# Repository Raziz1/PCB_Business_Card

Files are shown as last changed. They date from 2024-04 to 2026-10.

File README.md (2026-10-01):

# PCB Business Card 💳
The following project is a PCB designed as a business card. This card contains an integrated NFC tag that allows you to share your contact information wirelessly.

<p align="center">
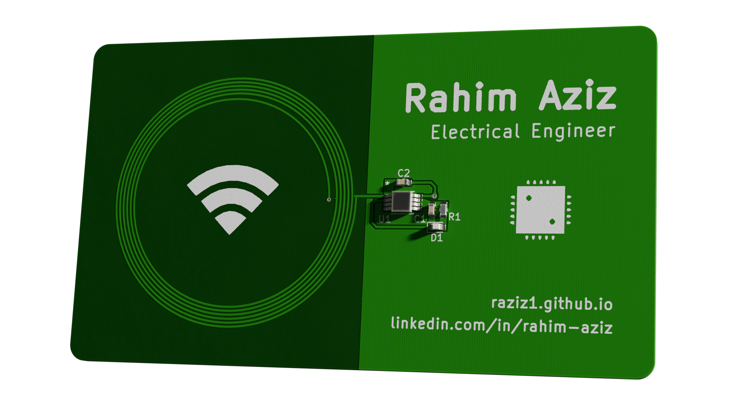
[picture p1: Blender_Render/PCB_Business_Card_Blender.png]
PCB Business Card PCB Business Card Render
    
</p>
<p align="center"><i>Blender Render</i></p>

## NFC Principle 🧲
<b>[NFC (Near Field Communication)](https://www.spiceworks.com/tech/networking/articles/what-is-near-field-communication/)</b> is a group of communication protocols that allows for low speed wireless communication between two electronic devices. 
* NFC communication occurs when both electronic devices are within a distance of 4cm or less. 
* NFC operates at 13.56 MHz on ISO/IEC 18000-3 air interface and at rates ranging from 106 kbit/s to 424 kbit/s.
* The transfer of data in NFC is bi-directional.
* NFC has a setup time of 0.1s. For reference, Bluetooth requires a setup time of 6s.
* NFC utilizes the phenomenon of inductive coupling between two electromagnetic coils.

<p align="center">
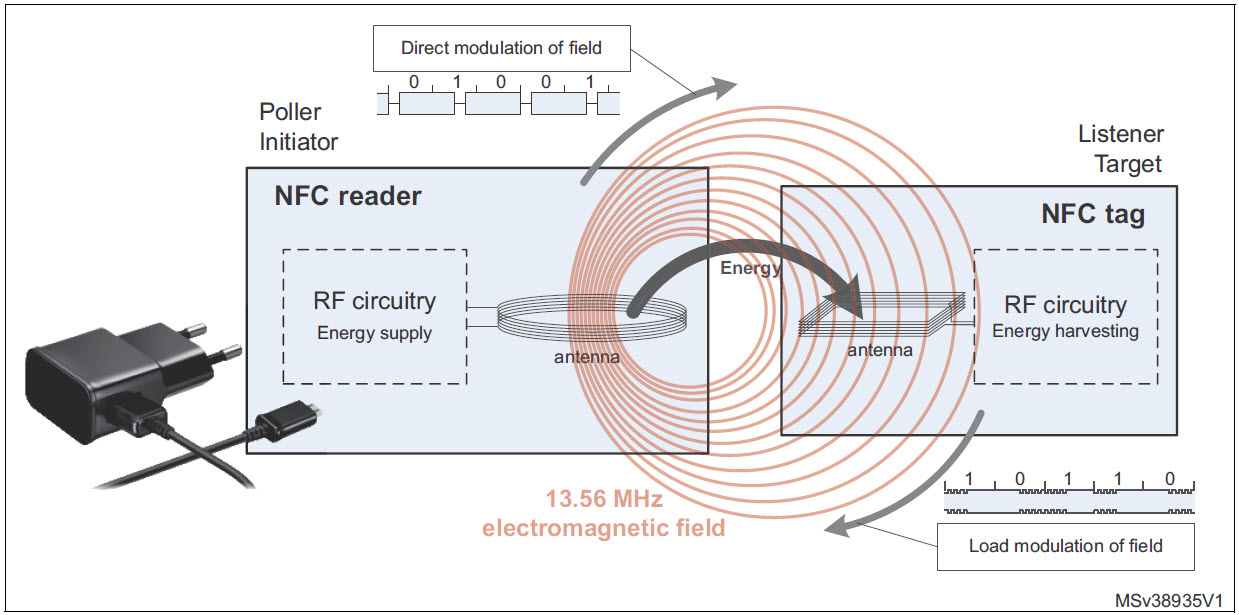
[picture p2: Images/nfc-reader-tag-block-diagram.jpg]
NFC Principle
    
</p>

## NFC IC 📶
THe NFC IC being used in this project is the [NT3H1101W0FTTJ](https://www.digikey.ca/en/products/detail/nxp-usa-inc/NT3H1101W0FTTJ/5347877).
* This chip is an NFC chip designed by NXP. It features I2C communication, energy harvesting, and field detection features. 
* It features 64 bytes of SRAM and 1kB of EEPROM memory. We can use the onboard memory to stored a personal website link for the user device to retrieve when communicating with the IC.
* Lastly with this chip, we can utilize the induced current to power the chip (i.e., energy harvesting).
* We can program the IC through the [NFC TagWriter by NXP](https://play.google.com/store/apps/details?id=com.nxp.nfc.tagwriter&hl=en_GB) app.

<p align="center">
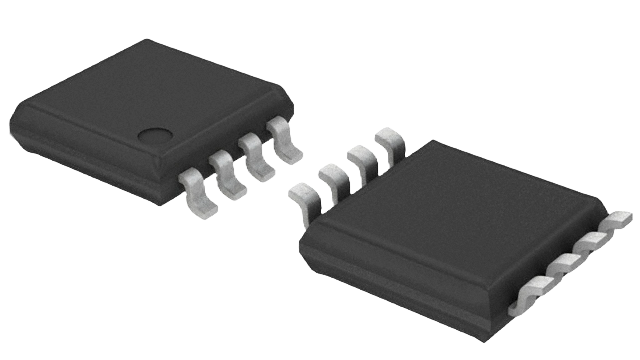
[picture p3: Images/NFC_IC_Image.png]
NFC IC NFC IC
    
</p>

## NFC Equivalent Circuit
The internet has a plethora of resources for antenna design. The two sources I will be referring to for this design are:
* [AN11276 - NXP Community](https://community.nxp.com/pwmxy87654/attachments/pwmxy87654/nfc/6155/1/AN11276.pdf)
* [AN2972 Application note How to design an antenna for dynamic NFC tags](https://www.st.com/resource/en/application_note/an2972-how-to-design-an-antenna-for-dynamic-nfc-tags-stmicroelectronics.pdf)

The figure below shows the equivalent electrical circuits of the dynamic NFC tag and its antenna.

<p align="center">
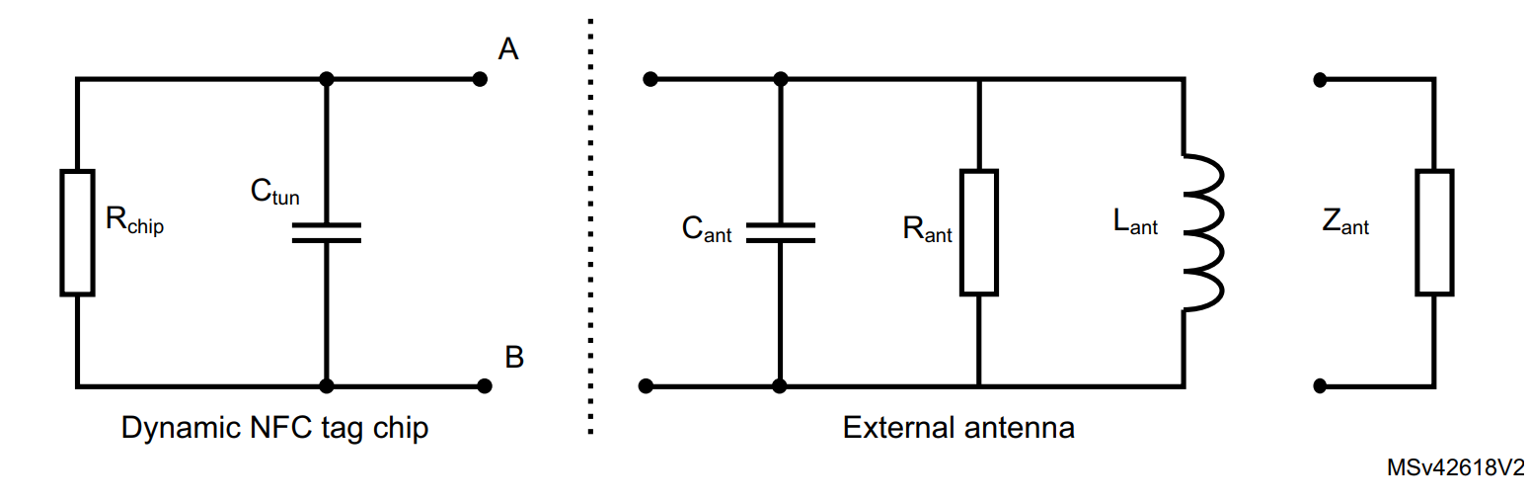
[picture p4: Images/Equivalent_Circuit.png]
NFC Equivalent Circuit
    
</p>

The above circuit can be simplified into an equivalent RLC circuit.

<p align="center">
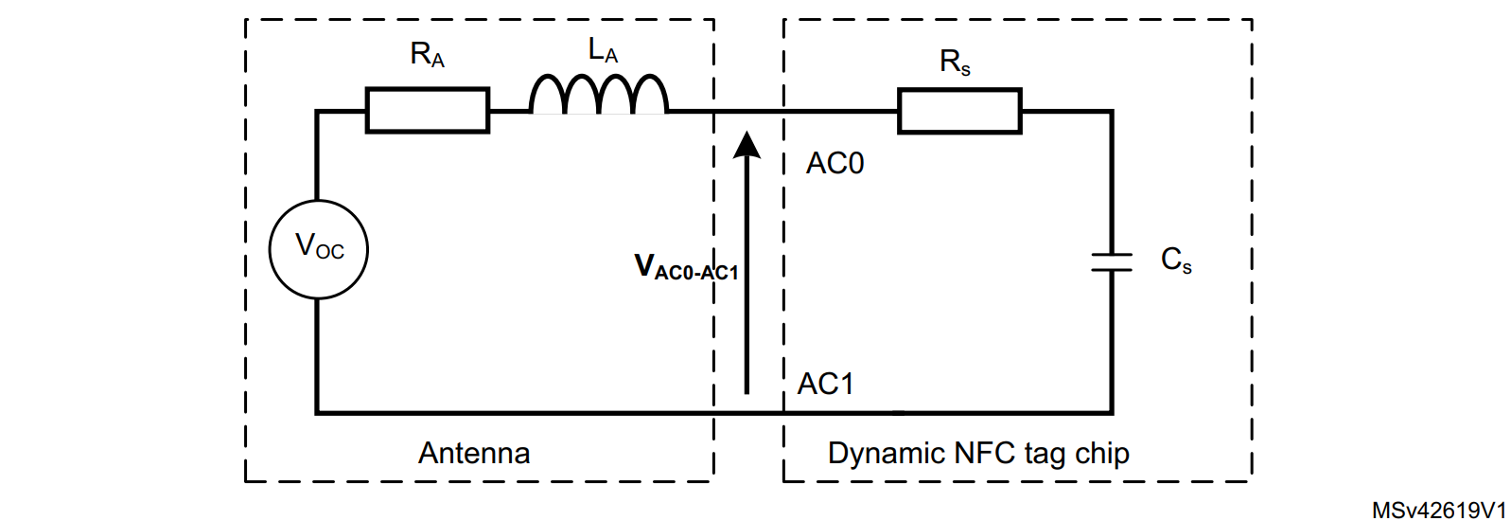
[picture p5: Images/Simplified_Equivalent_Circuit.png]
NFC RLC Circuit
    
</p>

### Resonance Frequency
Based on the simplified RLC circuit we can determine the resonant frequency. 
* Resonance frequency is the frequency (in hertz) in which a signal or power level can be carried, or couple from one device to another with no power or signal loss "ideally".
* $f_R=\frac{1}{2\cdot \pi \cdot \sqrt{L_{pc}\cdot C_{pl}}}$
    * $C_{pl}=C_{tun}+C_{ant}$

We know that for an NFC tag, the desired frequency is 13.56 MHz. We also know that the IC's parallel capacitance is 50 pF (from the datasheet). <i>Ignore the parasitic capacitance of the antenna for now; we will come back to that</i>. Based on this information, we can work backwards to determine the required inductance of the antenna.

$f_R=\frac{1}{2\cdot \pi \cdot \sqrt{L_{pc}\cdot C_{pl}}}$

$L_{pc}=\frac{1}{C_{pl}\left(2\pi f_R\right)^2}$

$L_{pc}=\frac{1}{5\cdot 10^{-11}\left(2\pi \cdot 13560000\right)^2} = 0.00000275518$

$L_{pc}=0.00000275518\:H=\:2.75518\:uH$

## Antenna Design 📡
We can now design an NFC antenna based on the desired inductance calculated above. To design the antenna I referred to various resources to confirm my calculations. 

### NXP Spiral Antenna Calculation
The [AN11276 NTAG Antenna Design Guide](https://community.nxp.com/pwmxy87654/attachments/pwmxy87654/nfc/6155/1/AN11276.pdf) provides the following information to design an antenna. 

<p align="center">
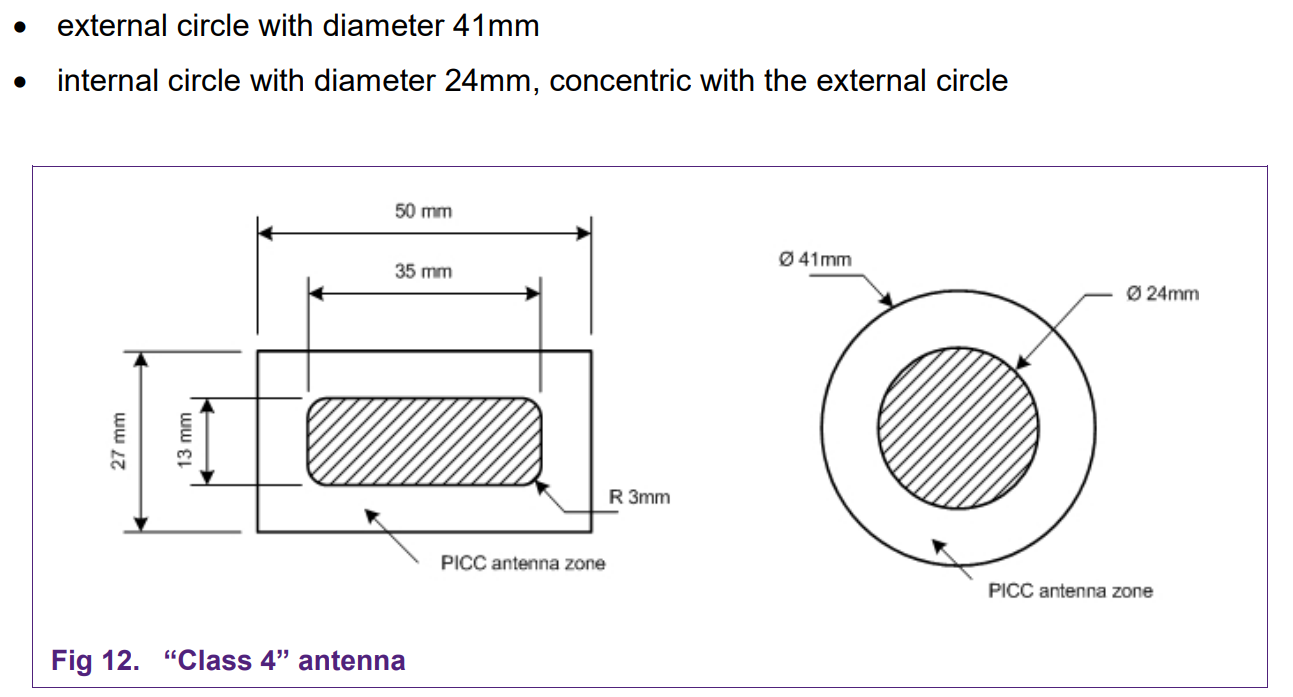
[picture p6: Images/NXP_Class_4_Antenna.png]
    
</p>
<p align="center"><i>NXP Class 4 Antenna Design Recommendation</i></p>

<p align="center">
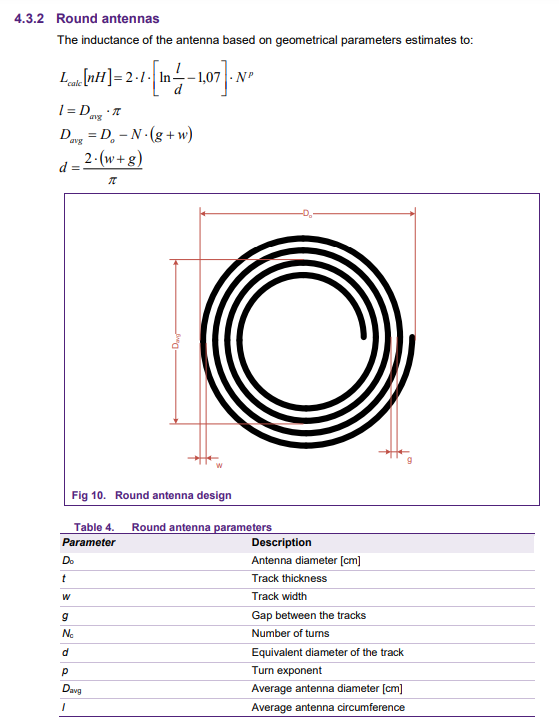
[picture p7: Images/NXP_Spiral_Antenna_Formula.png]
NXP Spiral Formula
    
</p>
<p align="center"><i>NXP Round Antennas Formula</i></p>

I utilized the [Antenna_Shape_Calculator](/Resource_Documents/Antenna_Shape_Calculator.xlsx) excel document to calculate the geometric parameters. They were as follows:
* $D_0 = 41mm$
* $t = 35um$
* $w = 300um$
* $g = 300um$
* $Nant = 6\:turns$
* $L_{calc} = 2.754uH$

### STM Spiral Antenna Calculation
The [AN2972 Application note](https://www.st.com/resource/en/application_note/an2972-how-to-design-an-antenna-for-dynamic-nfc-tags-stmicroelectronics.pdf) provides the following information to design an antenna. 

<p align="center">
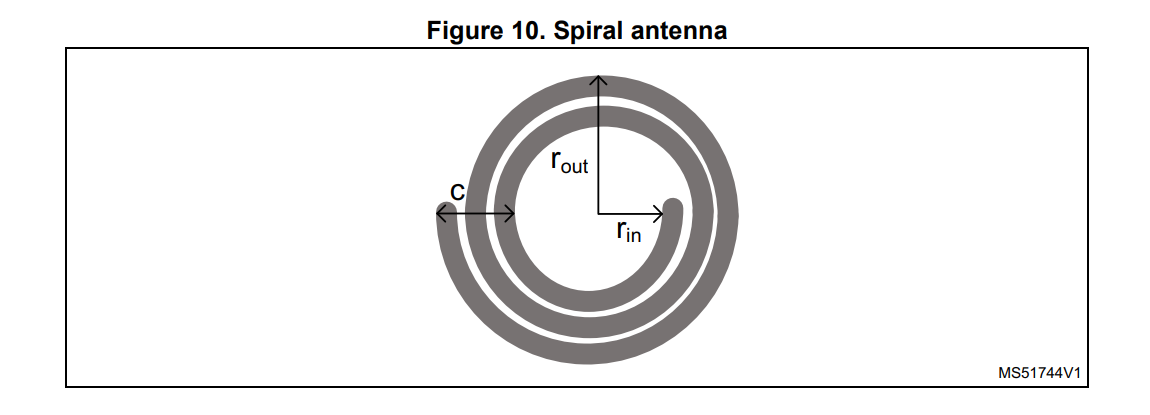
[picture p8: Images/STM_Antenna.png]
    
</p>
<p align="center"><i>STM Spiral Antenna Design</i></p>

<p align="center">
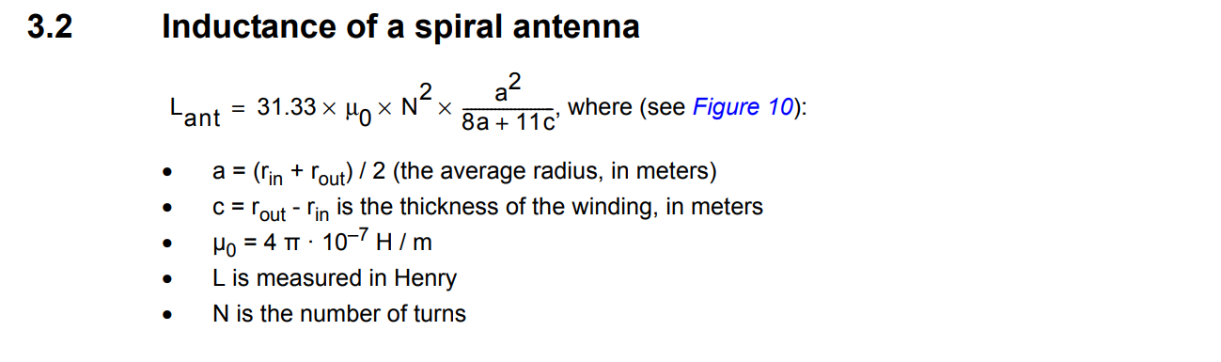
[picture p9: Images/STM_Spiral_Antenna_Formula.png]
STM Spiral Formula
    
</p>
<p align="center"><i>STM Spiral Antennas Formula</i></p>

I utilized the [Antenna_Shape_Calculator](/Resource_Documents/Antenna_Shape_Calculator.xlsx) excel document to calculate the geometric parameters. They were as follows:
* $r_{in} = 17.5mm$
* $r_{out} = 20.5mm$
* $Nant = 6\:turns$
* $L_{calc} = 2.766uH$

### Missing Parameters 
We are not quite ready to complete the design. Looking back at the equivalent circuit, we are still missing a few parameters: antenna capacitance, antenna resistance, and the NFC IC resistance. Typically, these parameters are determined by measuring the actual physical circuit design. For a guide on how to measure these parameters, check out the following link: --> [Guide to designing antennas for the NTAG I2C plus](https://community.nxp.com/t5/NXP-Designs-Knowledge-Base/Guide-to-designing-antennas-for-the-NTAG-I2C-plus/ta-p/1104729).  Nevertheless, we can make some rough estimations by utilizing various tools.

* Antenna resistance - By using a parasitic resistance tool in KiCad, we can calculate this parameter. According to the tool, the parasitic resistance was 1.17 ohms. 
* Antenna capacitance - By utilizing the [NXP NFC Antenna Tool](https://community.nxp.com/t5/NFC/bd-p/nfc/page/4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.) we can roughly estimate this parameter. This tool does not support spiral designs, but we can use the rectangular design to estimate this parameter. According to the tool, the parasitic capacitance was 1.9 pF.
* NFC IC Resistance - Assuming the voltage should drop entirely across the IC, we can consider this resistance to be infinitely large. For our purposes, we will estimate it to be 100k ohms.

<p align="center">
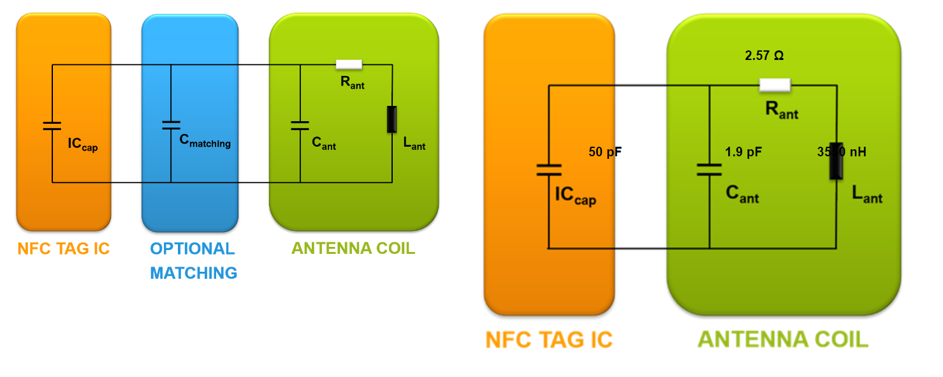
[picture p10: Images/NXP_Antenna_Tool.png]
NXP NFC Antenna Tool
    
</p>
<p align="center"><i>NXP NFC Antenna Tool</i></p>

## Simulation
We can now work our way backwards to verify the parameters we calculated above. By rebuilding the equivalent circuit with these parameters in LTSpice, we can verify the resonance frequency. According to the simulation below, the resonance frequency is 13.35 MHz. This should be adequate for NFC; alternatively, we can target an inductance of 2.5-2.6 uH to achieve a resonance frequency that is closer to 13.56 MHz. Furthermore, an optional tuning capacitor can be added to get closer to 13.56 MHz.

<p align="center">
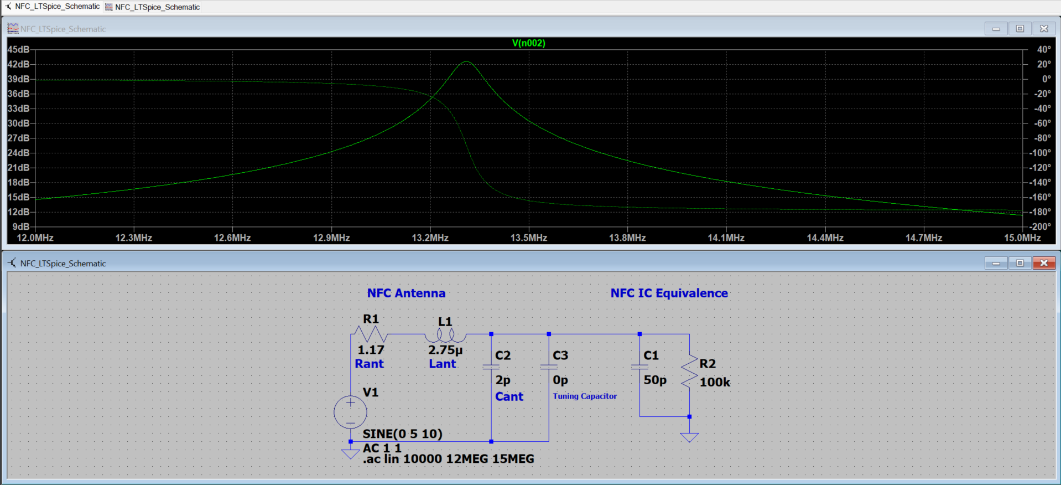
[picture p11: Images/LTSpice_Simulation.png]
LTSpice Simulation
    
</p>
<p align="center"><i>LTSpice Simulation</i></p>

I decided to rerun the simulation and redesign the antenna parameters ($D_0 = 39mm$) to target an inductance of 2.576uH. This gives us more headroom to account for any imperfections in the manufacturing process. This allows us to use a tuning capacitor to bring the resonance frequency down and closer to 13.56 MHz.  

<p align="center">
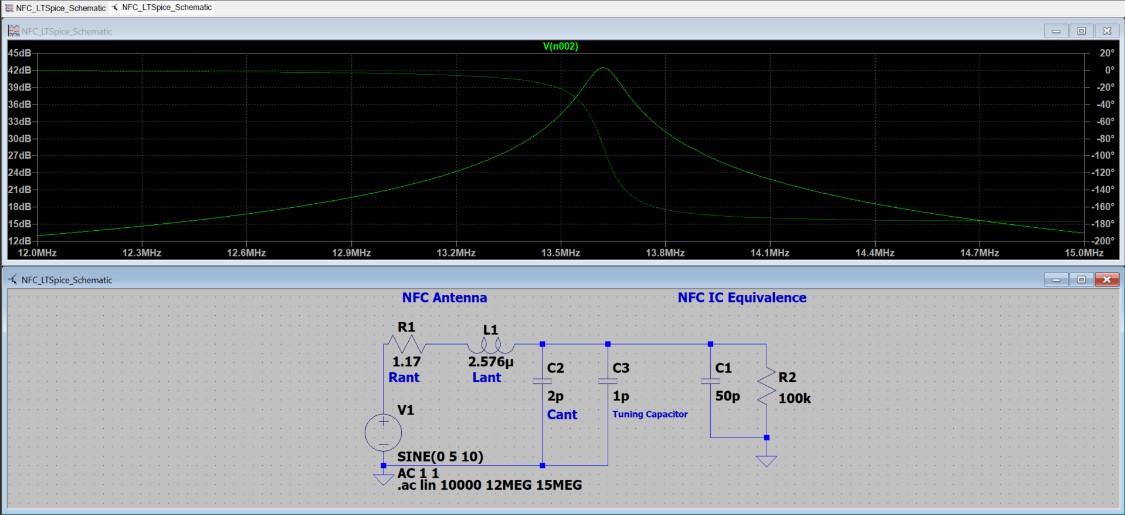
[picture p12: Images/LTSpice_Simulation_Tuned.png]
LTSpice Simulation Tuned
    
</p>
<p align="center"><i>LTSpice Simulation with Tuning Capacitor</i></p>

### Electromagnetic Simulation 🧲
Antennas are typically simulated using electromagnetic simulation software to predict and optimize their real-world performance. A variety of tools are available, such as:
* Ansys HFSS/Maxwell - The student edition is free but has limitations
* Solidworks CST Microwave -  The student edition is free but has limitations
* openEMS
* MATLAB Antenna Toolbox

For this design, I chose to work with MATLAB’s Antenna Toolbox and RF Toolbox, as I did not yet have the experience to effectively use industry-grade tools like HFSS or CST.

#### MATLAB Antenna Toolbox
<p align="center">
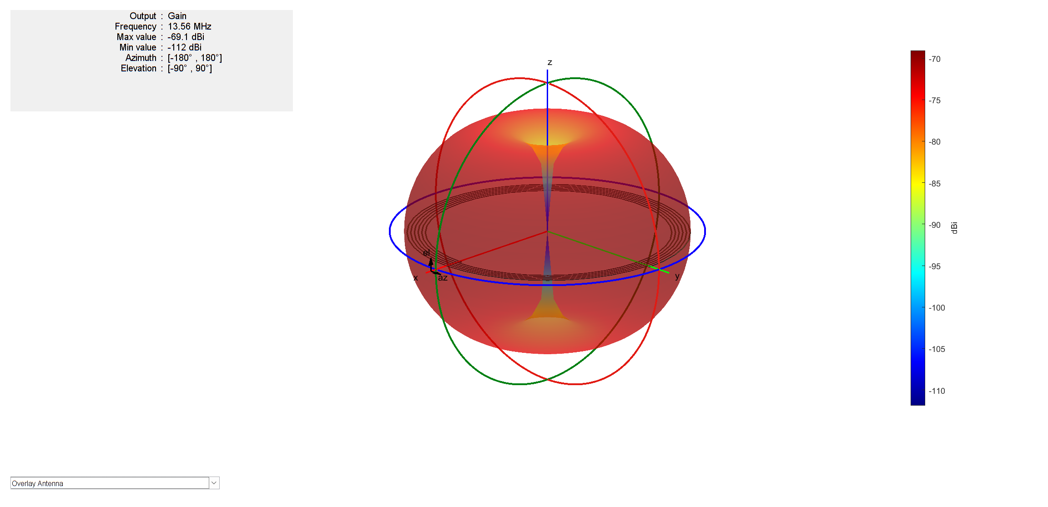
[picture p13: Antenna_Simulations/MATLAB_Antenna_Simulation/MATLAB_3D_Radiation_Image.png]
MATLAB Antenna Simulation
    
</p>
<p align="center"><i>MATLAB 3D Radiation Pattern</i></p>

After spending several days experimenting with the MATLAB script from the repository, I was unsuccessful in reproducing a clear resonance at 13.56 MHz. I tried designing the antenna directly in the Antenna Toolbox, carefully defining spiral coil parameters, trace width, spacing, and substrate properties. I also attempted to import the PCB layout into the PCB Antenna Toolbox using the gerber files of the actual NFC coil. Despite these efforts, the desired resonance could not be achieved. Following a discussion with [Umar on the MATLAB Answers forum](https://www.mathworks.com/matlabcentral/answers/2180231-matlab-nfc-antenna-simulation?s_tid=srchtitle), it was clarified that the limitation lies in the software itself for this specific application:

>* *"MATLAB’s Antenna Toolbox is designed for far-field radiation analysis, not near-field inductive coupling. NFC, however, operates in the reactive near-field, where antennas behave as coupled inductors rather than radiating elements. The S11 parameters calculated in MATLAB inherently assume radiation losses, which do not accurately represent NFC coil physics."* *

At this stage, Umar provided a toolbox-free MATLAB script that verified the design using RF first principles, which is available in the repository. The script addressed the following calculations:
* Inductance using Wheeler’s formula (adapted to spiral coil + substrate corrections)
* AC + DC resistance including skin effect and dielectric loss
* Impedance of the NFC IC (modeled as parallel R + C)
* Combined system impedance and S11 over a narrower frequency sweep
* Determination of resonant frequency (by finding minimum imaginary part)
* Computation of required tuning capacitance
* Quality factor (Q), VSWR, bandwidth, return loss, Smith chart, etc.
* Using this method, Umar was able to detect a resonance around 11.81 MHz (≈ 12.9% error relative to target) with realistic inductance, resistance, and matching parameters. 

<p align="center">
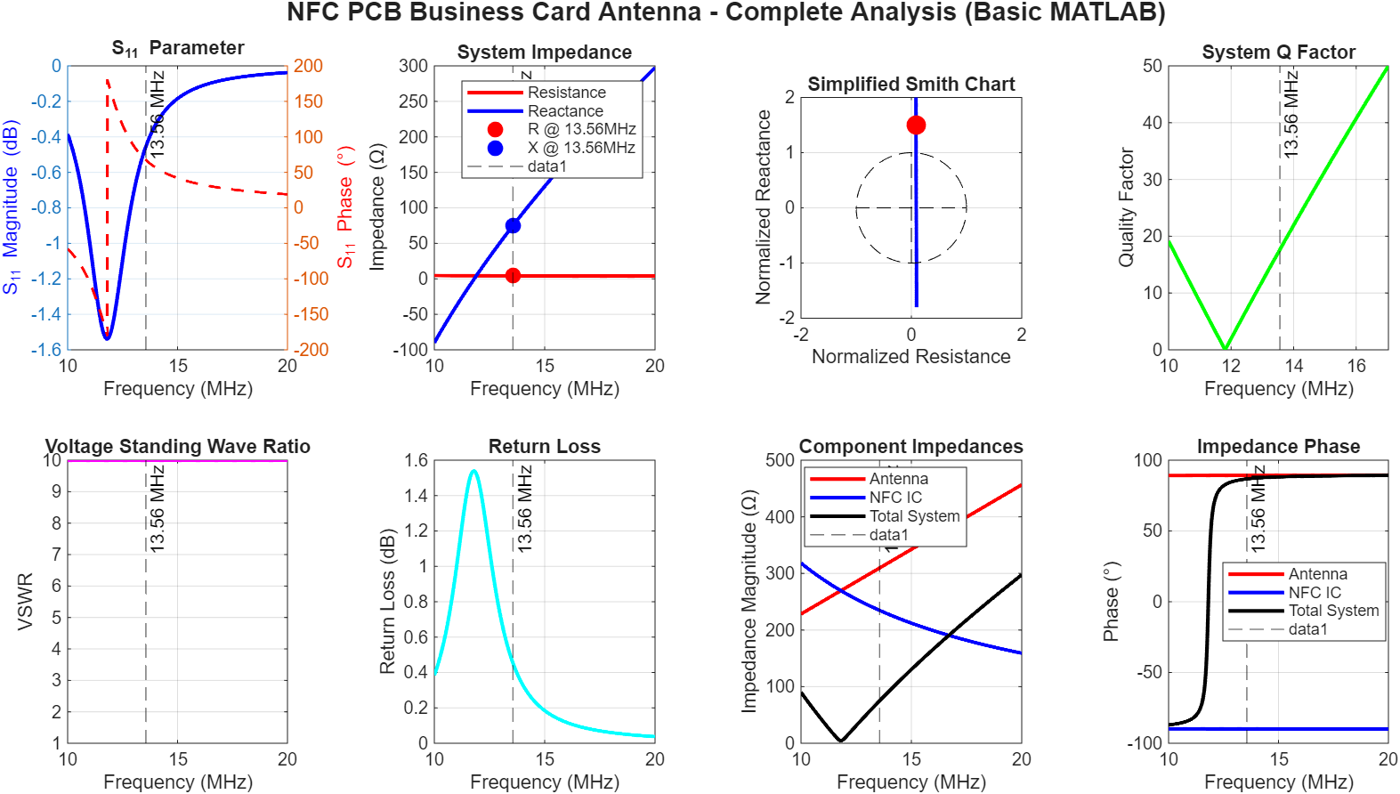
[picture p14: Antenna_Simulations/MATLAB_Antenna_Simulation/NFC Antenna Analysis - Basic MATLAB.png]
Umar Script Output
    
</p>
<p align="center"><i>Umar Script Output</i></p>

## PCB Design
For the final design of the antenna I ended up settling on the following parameters:
* $D_0 = 39mm$
* $t = 35um$
* $w = 300um$
* $g = 300um$
* $Nant = 6\:turns$
* $L_{calc} = 2.576uH$
* $R_{ant} = 1.17\:ohms$
* $C_{ant} = 2pF$
* $Simulated\:resonance\:frequency:\:13.75 MHz$ 
    * *Without Tuning Capacitor*

For the schematic, I borrowed the idea of an LED indicator for the energy harvesting circuit from the [PCB Business Card With NFC](https://www.instructables.com/PCB-Business-Card-With-NFC/). The capacitor is to guarantee operation during RF communication. The resistor value was chosen to limit the current going through the LED. The value was determined by using the following equation:
* $R\:=\:\frac{V_{CC}-V_{LED}}{I_{LED}}=\frac{3.3-2}{0.02} = 65Ω$

<p align="center">
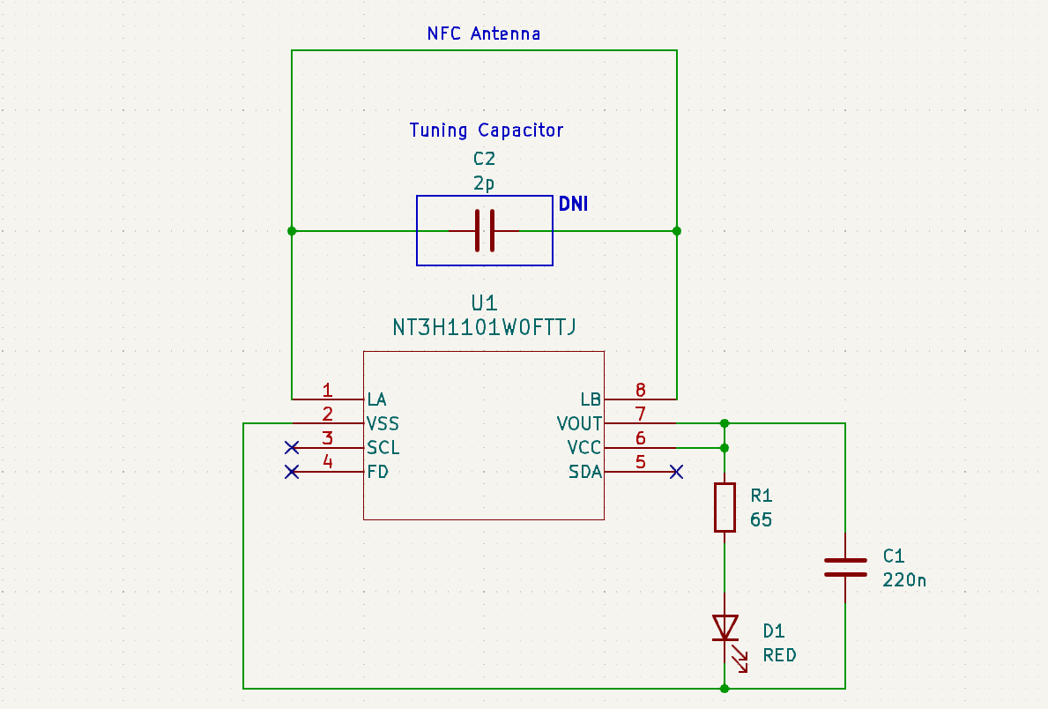
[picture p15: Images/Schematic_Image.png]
KiCad Schematic Design
    
</p>
<p align="center"><i>Schematic Design</i></p>
<p align="center">
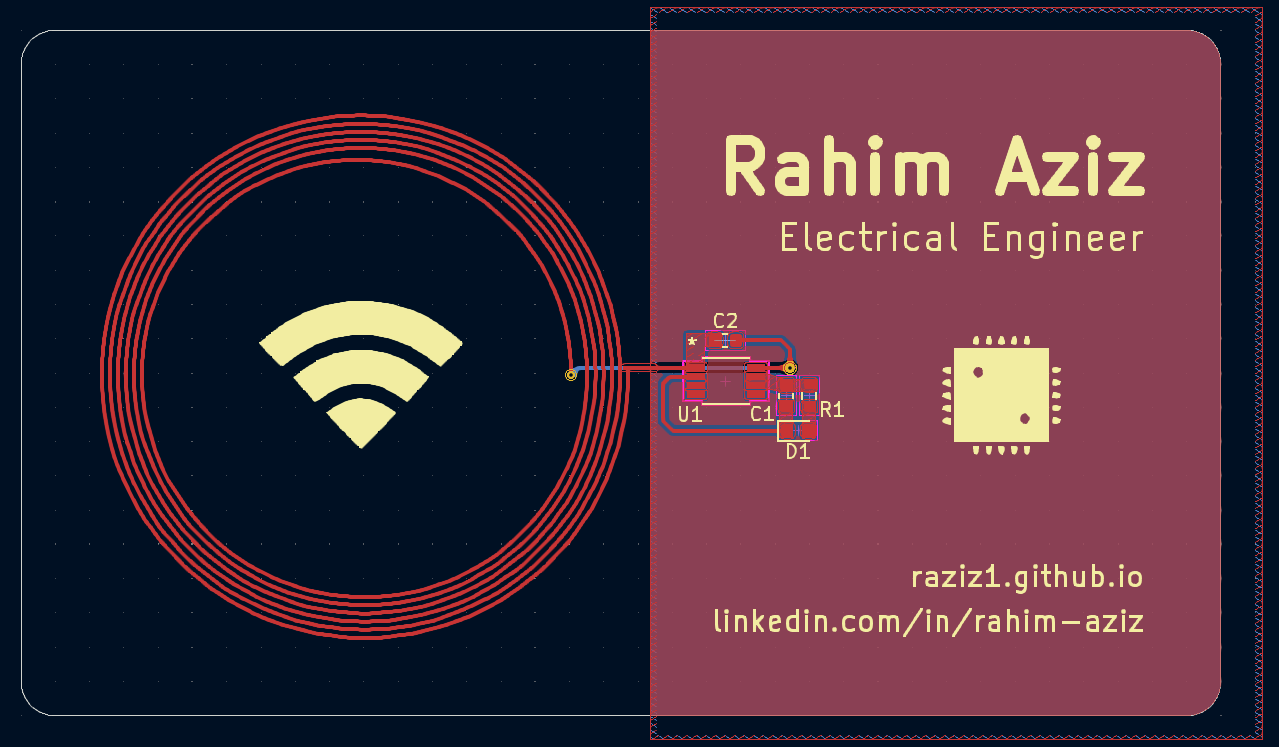
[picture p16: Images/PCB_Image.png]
KiCad PCB Design
    
</p>
<p align="center"><i>PCB Design</i></p>

## Final BOM 📃
* [NT3H1101W0FTTJ - IC RFID TRANSP 13.56MHZ 8TSSOP](https://www.digikey.ca/en/products/detail/nxp-usa-inc/NT3H1101W0FTTJ/5347877)
* [150060VS75000 - LED GREEN CLEAR 0603 SMD](https://www.digikey.ca/en/products/detail/w%C3%BCrth-elektronik/150060VS75000/4489906)
* [C0603C224J4REC7867 - CAP CER 0603 220NF 16V X7R 5%](https://www.digikey.ca/en/products/detail/kemet/C0603C224J4REC7867/8643651)
* [CRCW060364R9FKEA - RES SMD 64.9 OHM 1% 1/10W 0603](https://www.digikey.ca/en/products/detail/vishay-dale/CRCW060364R9FKEA/1174533)
* [GRM0335C1E1R5BA01D - CAP CER 1.5PF 25V C0G/NP0 0201 (0603 Metric)](https://www.digikey.ca/en/products/detail/murata-electronics/GRM0335C1E1R5BA01D/4358584)

## Manufacturing 🪛
I ordered the board through PCBWay by using the [KiCAD plugin](https://www.pcbway.com/blog/News/PCBWay_Plug_In_for_KiCad_3ea6219c.html). I assembled and soldered the components on the board myself. 

For the PCBWay specification selection I chose the following options:
* Layers: 2
* Material: FR-4
* FR4-TG: TG130-140
* Thickness: 1.6mm
* Min track/spacing: 5/5mil
* Solder mask: Green
* Silkscreen: White
* Edge connector: No
* Surface finish: HASL with lead
* Via process: Tenting vias
* Finished copper: 1 oz Cu
* Remove product Num: No

<p align="center">
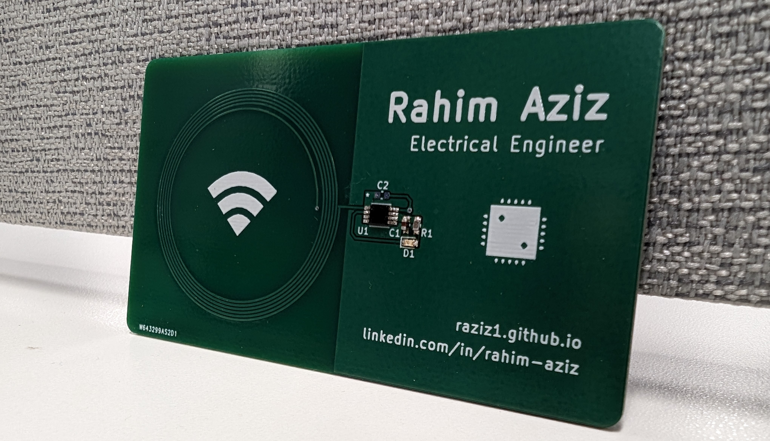
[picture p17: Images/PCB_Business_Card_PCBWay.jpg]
PCBWay PCB
    
</p>
<p align="center"><i>Final Product</i></p>

## Programming 💻
Lastly, I programed the IC through the [NFC TagWriter by NXP](https://play.google.com/store/apps/details?id=com.nxp.nfc.tagwriter&hl=en_GB) app.

<p align="center">
    PCB GIF
</p>
<p align="center"><i>PCB in Action!</i></p>

> [!CAUTION]
> ### iPhone Compatibility & Energy Harvesting Limit
>
> During real-world testing, this card worked reliably on Android devices but failed to trigger background NFC reading on iPhones.
>
> * **Polling Fields:** iPhones emit low-energy, brief polling bursts to conserve battery, whereas many Android phones broadcast significantly stronger, higher-energy continuous RF fields.
> * **Energy Starvation:** When attempting to harvest energy from an iPhone, the on-board LED circuit drew too much current. This collapsed the harvested voltage rail before the NT3H1101’s digital core could boot and complete its initial communication handshake.
>
> #### Circuit Current Consumption
> Based on the populated components ($R = 64.9\ \Omega$ and a green LED with $V_f \approx 2.0\text{ V}$), the branch demands:
>
> $$I_{LED} = \frac{V_{OUT} - V_{LED}}{R} = \frac{3.3\text{ V} - 2.0\text{ V}}{64.9\ \Omega} \approx 20\text{ mA}$$
>
> #### Datasheet Limit
> According to the NXP NT3H1101/1201 datasheet:
>
> > *"The voltage and current from the energy harvesting depend on various parameters, such as the strength of the RF field, the tag antenna size, or the distance from the NFC device. At room temperature, NTAG I2C could provide typically 5 mA at 2 V on the VOUT pin with an NFC Phone.*
> >
> > *Operating NTAG I2C in energy harvesting mode requires a number of precautions:*
> > * *A significant capacitor is needed to guarantee operation during RF communication. The total capacitor between VOUT and GND shall be in the range of 150nF to 200 nF.*
> >
> > *Note that increasing the output current on the Vout decreases the RF communication range."*
>
> Because the IC typically delivers only up to **5 mA at 2 V** under smartphone coupling, an active load demanding **~20 mA** collapses the harvested rail on lower-power emitters like iPhones.
>
> **Fix:** Leaving the LED/resistor unpopulated (or increasing the resistor to $\ge 1\text{--}2\text{ k}\Omega$ to limit current below $1\text{ mA}$) immediately restores instant background read compatibility on iPhones.

## Characterization 🔬
Finally, I wanted to characterize the response of the circuit using my Analog Discovery 2 - USB oscilloscope. In particular, I aimed to characterize and visualize the difference in responses when the circuit had and didn't have a tuning capacitor.

### No Tuning Capacitor

The first order of business was to utilize the network analyzer feature on the Analog Discovery 2. By attaching the wave generator on one end of the antenna and probing on the other we could sweep through various frequencies and observe the circuits response.

<p align="center">
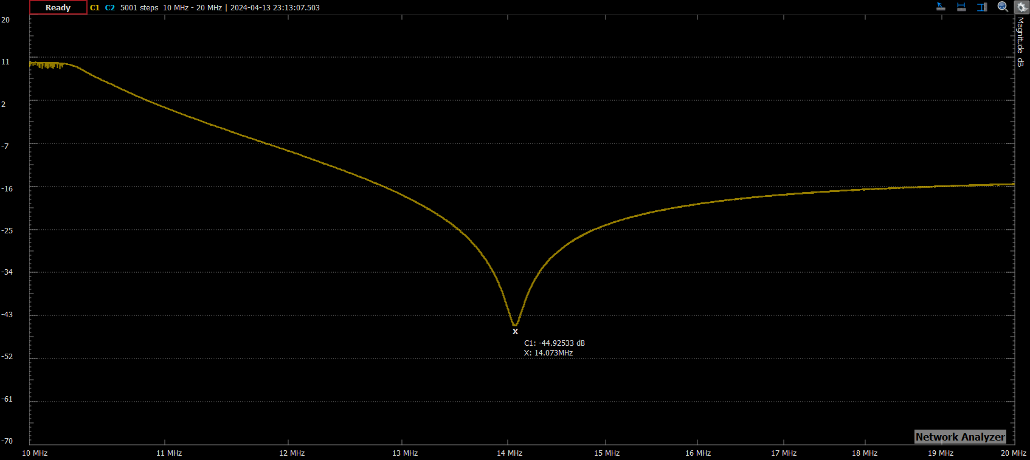
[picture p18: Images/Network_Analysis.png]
Network Analyzer
    
</p>
<p align="center"><i>Network Analyzer</i></p>

The above graph describes the S11 parameter, which represents the return loss of a device, indicating how much of the input power supplied to the device reflects back to the input port. We observe that at 14 MHz, the graph dips to a gain of -44.9 dB. This indicates that at 14 MHz, the magnitude of the reflected signal is lower than the magnitude of the incident signal. This implies that the antenna is absorbing the incident energy rather than reflecting it back towards the source. This response closely matches what we simulated previously in LTspice and MATLAB. For an NFC antenna, this behavior is desirable at 13.56 MHz. We can generate a graph with a dip closer to 13.56 MHz by including the tuning capacitor!

<p align="center">
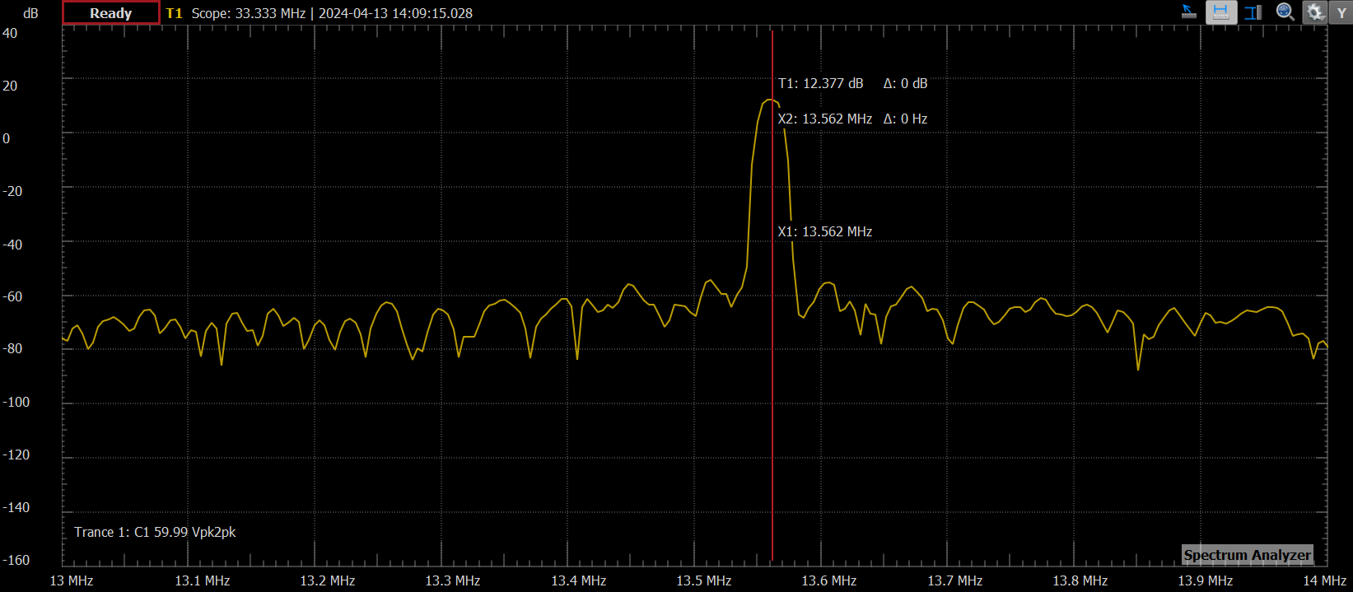
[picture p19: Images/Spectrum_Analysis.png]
Spectrum Analyzer
    
</p>
<p align="center"><i>Spectrum Analyzer</i></p>

Lastly, during the operation of the circuit, we can utilize the spectrum analyzer to observe the magnitude of the incoming signal. Keep in mind that this circuit doesn't contain a tuning capacitor. This was achieved by probing both ends of the antenna. Once a phone was brought within operating distance, we could see that the antenna contained a signal with a magnitude of 12.37 dB at 13.56 MHz.

### Tuning Capacitor Included (3.9pF)

By introducing a tuning capacitor with a value of 3.9pF, I was able to adjust the circuit's response to achieve resonance closer to the NFC standard of 13.56 MHz. Below is the graph produced by the network analyzer. We can see that this time the graph dips at a frequency of 13.555 MHz with a gain of -44.34 dB.

<p align="center">
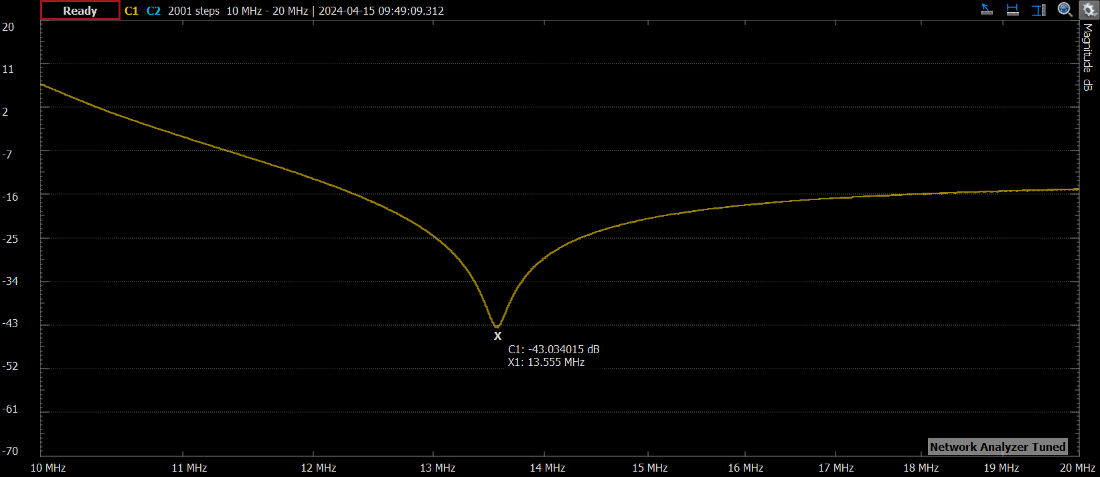
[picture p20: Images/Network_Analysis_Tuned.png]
Network Analyzer Tuned
    
</p>
<p align="center"><i>Network Analyzer</i></p>

<p align="center">
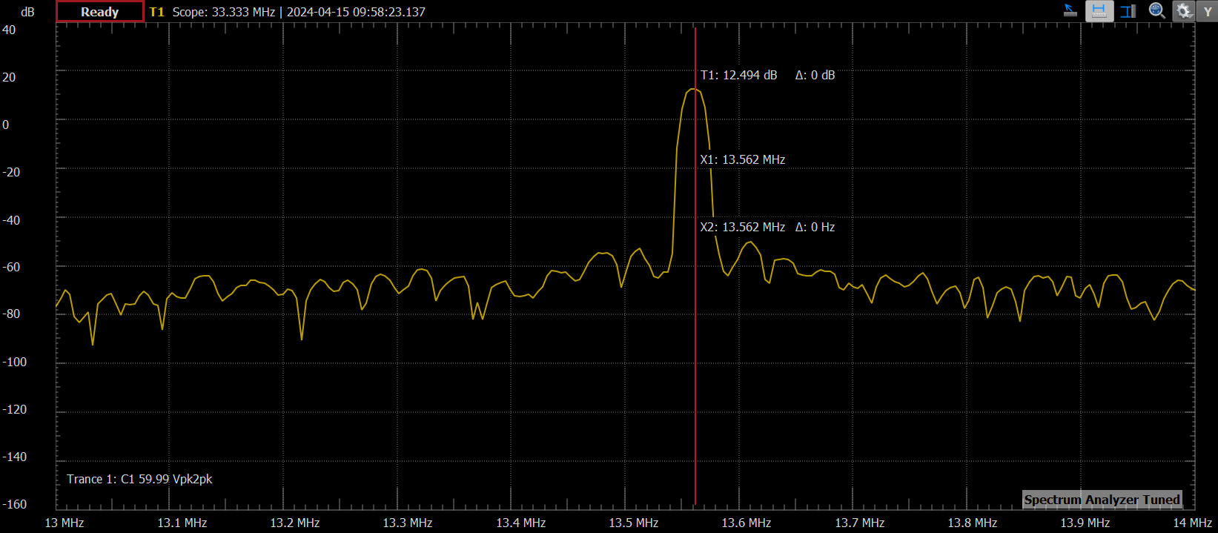
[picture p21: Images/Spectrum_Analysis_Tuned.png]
Spectrum Analyzer Tuned
    
</p>
<p align="center"><i>Spectrum Analyzer</i></p>

Utilizing the same process as the previous spectrum analysis, we can observe that the antenna contained a signal with a magnitude of 12.494 dB at 13.562 MHz.

### Poorly Tuned NFC Antenna
By introducing a really large tuning capacitor with a value of 15pF, we can adjust the circuit's response to achieve resonance at 12.5 MHz. Given the poorly tuned antenna, we expect to either see that the NFC capabilities cease to work or that the magnitude of the NFC signal is extremely weak. We can quantify this by utilizing the same spectrum analysis technique as used in the previous examples.

<p align="center">
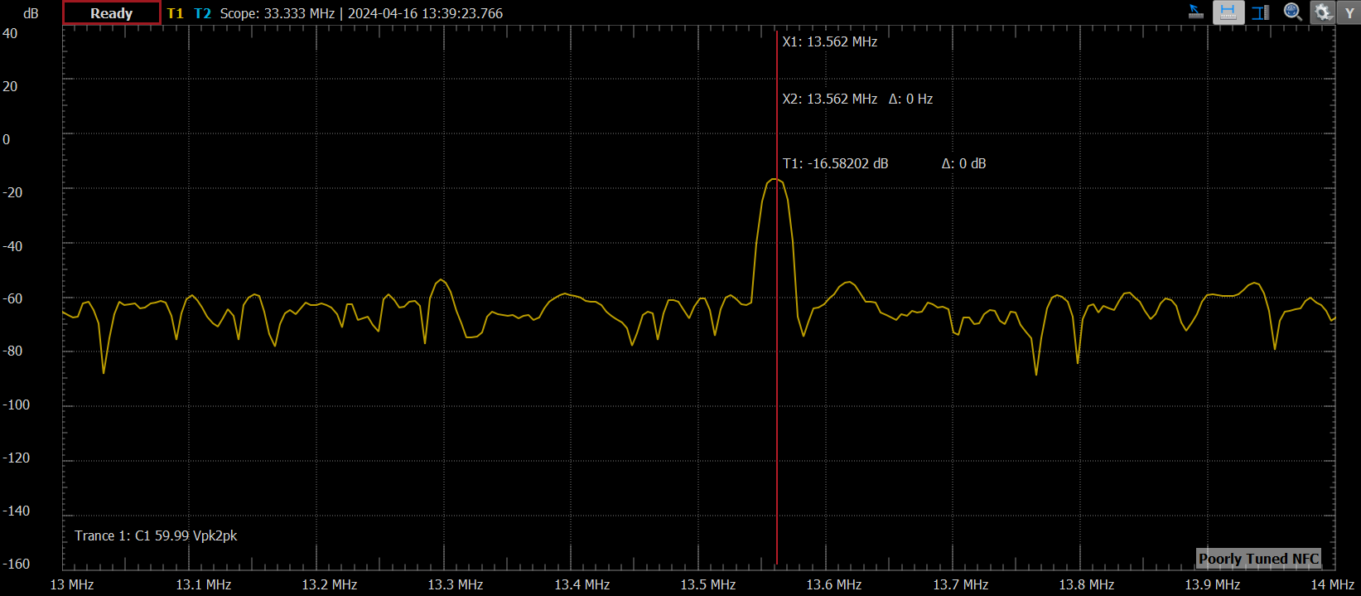
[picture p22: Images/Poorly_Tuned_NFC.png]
Spectrum Analyzer Poorly Tuned
    
</p>
<p align="center"><i>Spectrum Analyzer of Poorly Tuned Antenna</i></p>

With the poorly tuned antenna, the NFC capabilities continued to work. However, it did require the phone to be slightly closer to the antenna. Additionally, based on the above graph, we can see that the magnitude of the NFC signal (13.56MHz) is significantly weaker than in previous examples.

## NFC Protocol
By utilizing the Analog Discovery 2 oscilloscope feature, I was able to capture a snippet of an NFC transmission. This was done by probing the antenna during NFC operation. The NFC protocol is extremely complicated, and therefore, it is difficult to decipher what this transmission is. You can click on the following link to learn more about the [NFC transmission protocol](https://scdn.rohde-schwarz.com/ur/pws/dl_downloads/dl_application/application_notes/1ma182/1MA182_5E_NFC_WHITE_PAPER.pdf).

<p align="center">
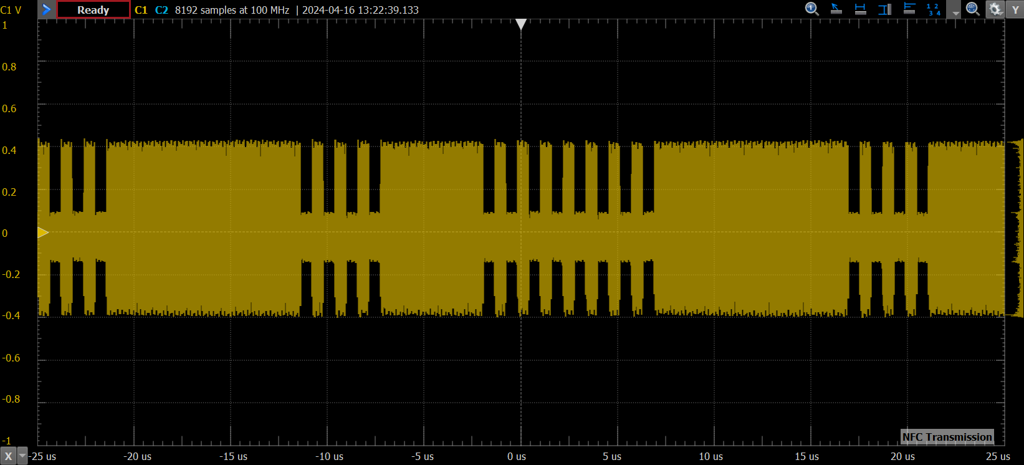
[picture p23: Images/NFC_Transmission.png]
NFC Transmission
    
</p>
<p align="center"><i>NFC Transmission</i></p>

# Resources
* [Guide to designing antennas for the NTAG I2C plus
](https://community.nxp.com/t5/NXP-Designs-Knowledge-Base/Guide-to-designing-antennas-for-the-NTAG-I2C-plus/ta-p/1104729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)
* [PN7160 antenna design and matching guide](https://www.nxp.com/docs/en/application-note/AN13219.pdf)
* https://github.com/shawnalexsony/Business_Card_PCB/tree/main
* [PCBWAY Custom Design Rules Templates](https://www.pcbway.com/pcb_prototype/PCB_Design_Rule_Check.html?currency=1)

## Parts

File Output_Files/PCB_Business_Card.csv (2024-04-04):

Id | Designator | Footprint | Quantity | Designation | Supplier and ref
1 | C1 | C_0603_1608Metric | 1 | 220n
2 |  |  | 1
3 | U1 | TSSOP8_SOT505-1_NXP | 1 | NT3H1101W0FTTJ
4 | REF** | COIL_GENERATOR | 1 | COIL_GENERATOR
5 | C2 | C_0603_1608Metric | 1 | 2p
6 | R1 | R_0603_1608Metric | 1 | 47
7 | D1 | LED_0603_1608Metric | 1 | RED

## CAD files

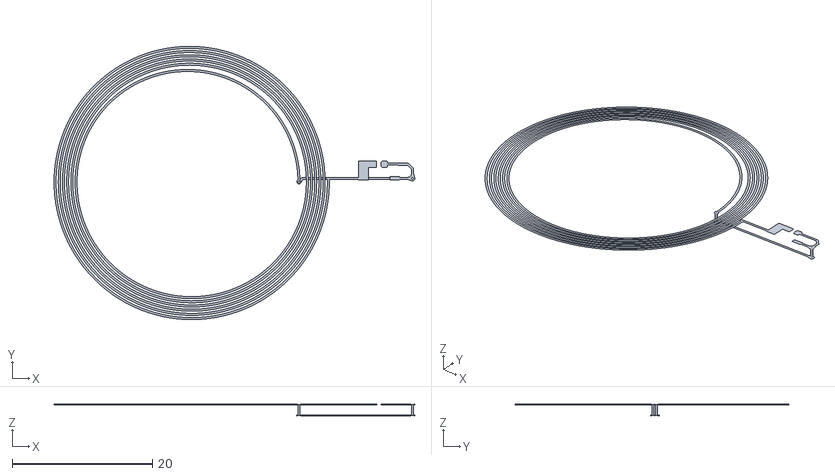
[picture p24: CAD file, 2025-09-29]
Antenna_Simulations/MATLAB_Antenna_Simulation/PCB_Coil_STL.stl
51.5 x 39.0 x 1.59

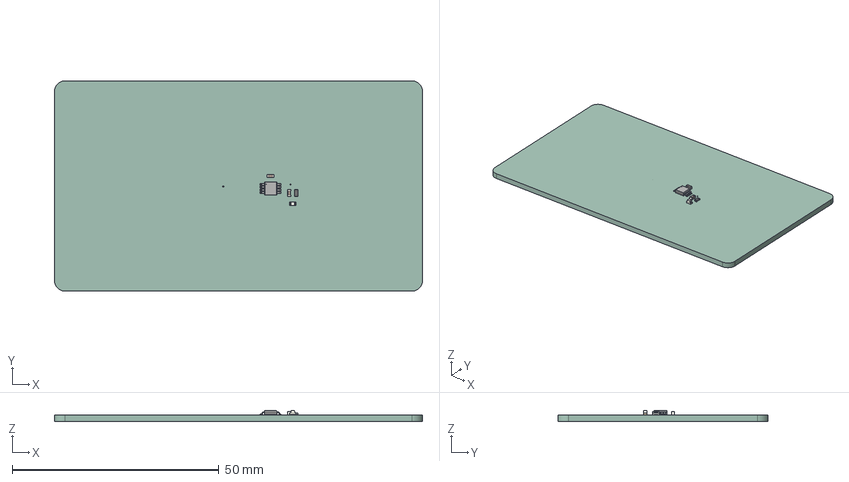
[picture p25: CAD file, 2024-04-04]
Blender_Render/PCB_Business_Card_STEP.step
88.9 x 50.8 x 2.75 mm
C_0603_1608Metric x 2
R_0603_1608Metric
LED_0603_1608Metric
PCB_Business_Card_PCB

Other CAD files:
Blender_Render/PCB_Business_Card.blend

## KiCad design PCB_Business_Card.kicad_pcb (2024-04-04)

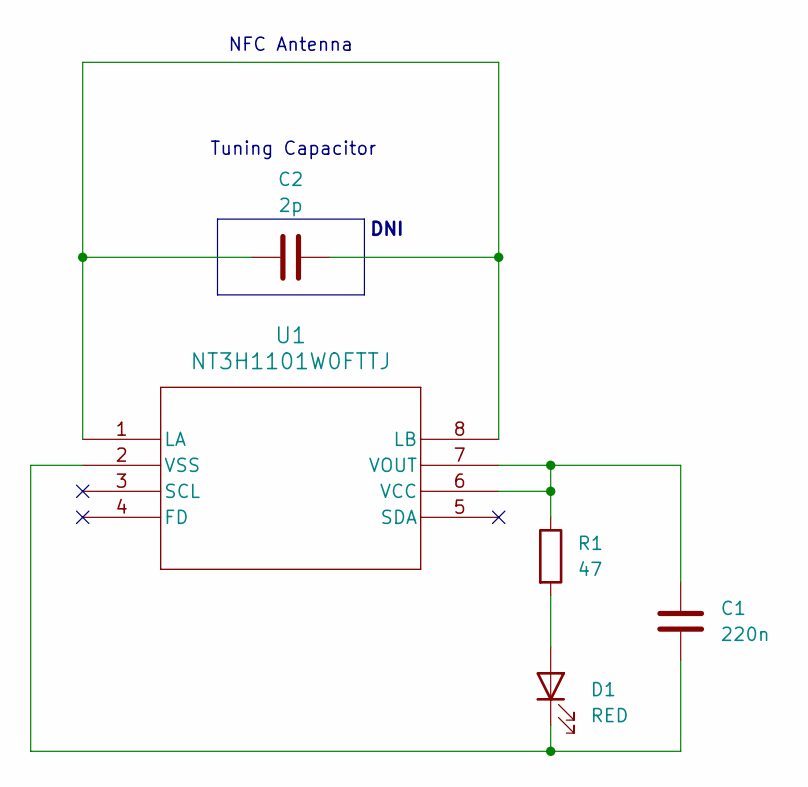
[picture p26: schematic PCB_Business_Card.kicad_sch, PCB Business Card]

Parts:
C1: 220n; C_0603_1608Metric
C2: 2p; C_0603_1608Metric
D1: RED; LED_0603_1608Metric
R1: 47; R_0603_1608Metric
U1: NT3H1101W0FTTJ; TSSOP8_SOT505-1_NXP

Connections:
unnamed: D1.2 (A), R1.2
unnamed: C1.2, D1.1 (K), U1.2 (VSS)
unnamed: C2.1, C2.2, U1.1 (LA), U1.8 (LB)
unnamed: C1.1, R1.1, U1.6 (VCC), U1.7 (VOUT)

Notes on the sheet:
DNI
NFC Antenna
Tuning Capacitor

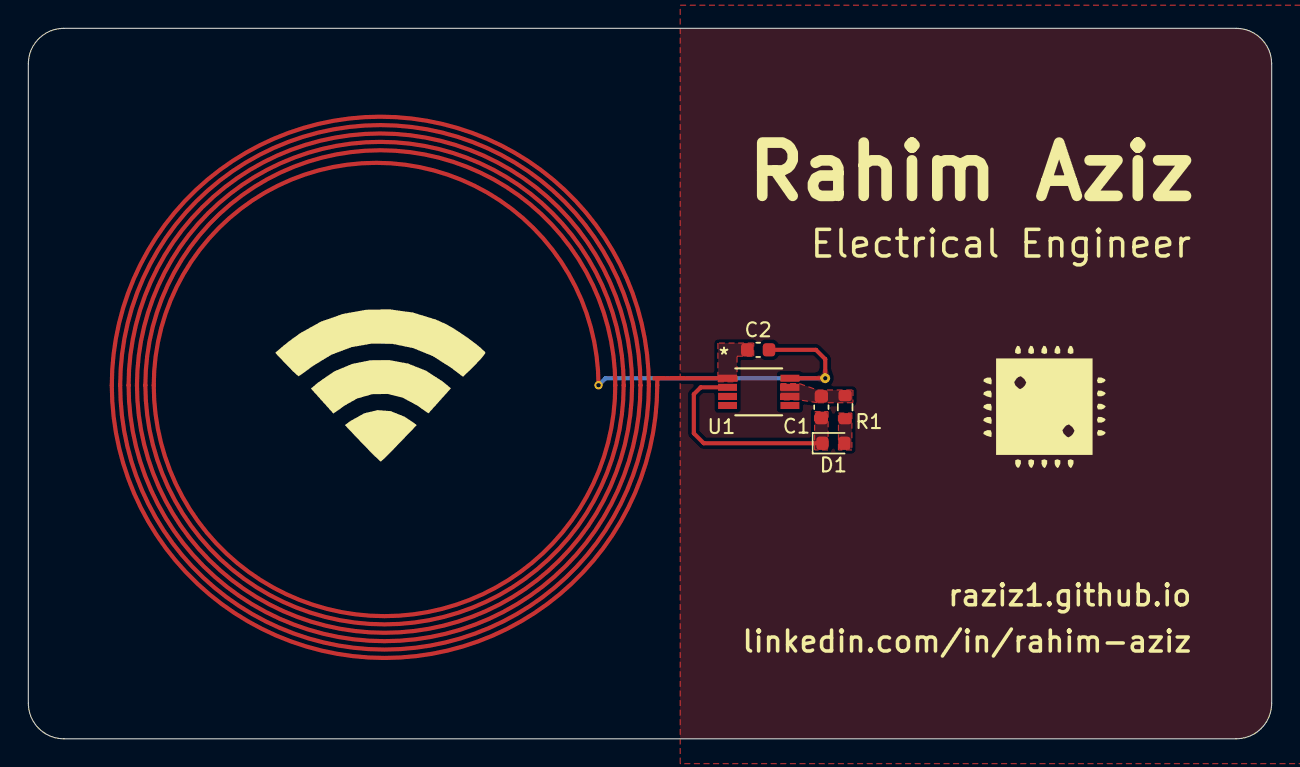
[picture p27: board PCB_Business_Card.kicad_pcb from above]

Board: 2 copper layers, 88.9 x 50.8 mm, 5 parts (0 on the bottom side), 4 nets.

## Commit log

2024-04-03 Updated Render
    [PCB_Business_Card.blend, PCB_Business_Card.kicad_pcb, PCB_Business_Card.kicad_sch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]
2024-04-04 Generated Gerber files
    [Antenna_Shape_Calculator.xlsx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]
2024-04-04 Added tuning capacitor
    [Antenna_Shape_Calculator.xlsx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]
2024-04-14 Circuit Response
    * Network analyzer graph
    * Spectrum analyzer graph
    [PCB_Business_Card.kicad_sch]
2024-04-14 Updated LED resistor
2024-04-15 Tuning capacitor results
2024-04-16 NFC transmission & Poorly tuned antenna
2025-09-29 Updated EM simulation
    [PCB_Coil_STL.stl]
2026-10-01 Document iPhone compatibility and energy harvesting issues
    Added section on iPhone compatibility and energy harvesting limits, including current consumption calculations and datasheet information.
